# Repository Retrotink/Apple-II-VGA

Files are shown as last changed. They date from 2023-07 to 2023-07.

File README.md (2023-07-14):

<br>appleIIvga github logo
<br>


<br>

This project is a VGA card for Apple II/II+ and //e computers to output a crisp RGB signal to a VGA monitor instead of having to rely on the composite output. This is accomplished by snooping the 6502 bus and creating a shadow copy of the video memory within a Raspberry Pi Pico, then processing the raw video memory contents to output a "perfect" signal. 
<br>
installed
<br>
These features are currently supported:<br>
Generates a 640x480@60 VGA signal with 3 bits per color channel using resistor DACs<br>
Text mode (monochrome)<br>
Lo-res mode with no color fringing between the chunky pixels<br>
Hi-res mode with simulated NTSC artifact color<br>
Mixed lo-res and hi-res modes with monochrome text and no color fringing<br>
Double hi-res and 80 column mode on the //e only<br>
screen demo
<br>

<br>
# Bill Of Materiels<br>
<br>
<br>

BOM

<br>
<br>

# Apple IIe internal Cable<br>

<br>

IIe cable

<br>
<br>

## AMAZON<br>

https://www.amazon.com/dp/B07W3ZTPZ6?psc=1&ref=ppx_yo2ov_dt_b_product_details
<br>

# Soldering the Apple II VGA Card
<br>

## Step 1: The Resistors<br>
resistor
<br>
Resistors are not polarized so they can be installed either direction. I like to start with the 100ohm resistors and work my way up to the 10K ohm resistors. The gold band is the percentage of accuracy. To read a resistor, start at the opposite side of the gold band.<br>
<br>
47 ohm resistors -- qty 2 - Colors Yellow Violet Black<br>
510 ohm resistors - qty 3 - Colors Green Brown Brown<br>
1K ohm resistors -- qty 6 - Colors Brown Black Red<br>
2K ohm resistors -- qty 3 - Colors Red Black Red<br>
10K ohm resistors - qty 4 - Colors Brown Black Orange<br>
Bend the metal wires at a 90 degree angle on each side of the resistor body.<br>
Place the resistor into the resistor location until it is flush with the PCB. <br>
Turn the board over holding the resistor in its place and bend the wires outward just slightly so the resistor can not back out of the holes. <br>
While the bottom of the board is facing up flat on your workspace, solder each of the two wires on the resistor. <br>
Make sure your solder stays only on the resistor wire and the hole. <br>
Cut the excess lead off the resistor. Repeat this procedure for all of the resistors.<br>
<br>
## Step 2: The Voltage Regulator<br>
vr
<br>
Insert the Voltage Regulator and fold it over so it lays flat on its back.<br>
Place the small screw into the top hole and through the board.<br>
Place the nut on the screw on the back of the board and tighten down.<br>
Solder all 3 pins and cut the extra leads short with the board.<br>
<br>
## Step 3: Install the three 20 pin sockets<br>
socket<br>
The socket has a notch on one end that matches the PCB.<br>
Place one socket into position and while holding the socket, turn the board over and lay flat on the table.<br>
Hold the board level and solder 1 pin down. Turn the board over and check that the board is flush with the PCB.<br>
If not, apply heat to the pin while pushing the socket flush to the PCB<br>
Solder the remaining pins on the socket and repeat for the other 2 sockets<br>
<br>
## Step 4: Install the 3 .1uF capacitors<br>
cap 1

Install the three .1uF caps into their locations. The caps are labeled 104 and are not polarized so they can be installed either way.<br> 
Fit as flush as possible, bend the 2 wires apart a little so the capacitor does not fall out, turn the board over and set it on your workspace. <br>
Solder the leads onto the PCB and cut away the excess lead length.<br>
<br>
## Step 5: Install the 10uF Electrolytic Capacitor<br>
cap10

## CAUTION: The capacitor is polarized and must be installed correctly. <br>
It is cylinder shaped and both leads protrude from the same side and are labeled 10uF. <br>
There are two ways to tell the + and - leads. <br>
First, looking at the leads, the + is longer than the – lead. <br>
Secondly, there is a large white arrow pointing to the - lead. <br>
Install flush with the PCB and fold it over so it lays between the .1uF cap and the voltage regulator.<br>
Then bend the two leads slightly apart from one another. <br>
Turn the board over and solder onto the PCB. Cut the excess lead on the capacitor.<br>
<br>
## Step 6: Install the Raspberry Pi Pico board<br>
pico
<br>
<br>
## CAUTION: Verify correct orientation before soldering down the Rasperry Pi Pico!<br>
Place the two 20 pin stand offs onto the board.<br>
Then place the Pico onto the stand offs and make sure everything fits flush.<br>
The Pico should be facing with the USB connector towards the VGA connector location.<br>
Solder the 40 pins onto the Pico then hold down the Pico, flip the board and solder the pins to the PCB<br>
<br>
## Step 7: Install the VGA connector<br>
vga

The VGA connector has 3 rows of pins. <br>
Insert flush with PCB, turn and solder the inside row first, followed by the outer 2 rows. <br>
Check your work, and then solder the support tabs down.<br>
<br>
## Step 8: Install the 74LVC245 Buffer IC's into the sockets<br>
You will need to pin the pins slightly inwards to align with the sockets.<br>
## CAUTION: Make sure all the IC's are facing towards the Voltage Regulator.<br>
Check for bent pins. Check for missing solder points<br>
<br>
## Solderfest 202/// all Pico chips are preprogrammed for the apple //e and will work on the apple ][ plus<br>
<br>
If you wish to program or update:<br>
1. Press and hold the BOOTSEL button on the Pico while plugging into PC<br>
2. A drive will appear on the PC called RPI-RPI2. Simply drag the *.UF2 firmware file to the RPI drive. <br>
3. The RPI drive will then disappear<br>
4. Remove the USB cable place the Apple ][ VGA card in your Apple ][
<br>

## Acknowledgements

Original design by Mark Aikens. Some minor modifications were made and a board layout made using original PI Pico source code. All parts are through hole for easy assembly. No surface mount components, simple to build.
<br>
https://github.com/markadev/AppleII-VGA
<br>
## Build at your own Risk

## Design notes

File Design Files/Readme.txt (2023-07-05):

Board size: 4.5W X 2.5H

Files:

AppleIIVGAf.GBL	Bottom Layer
AppleIIVGAf.GBS	Bottom Solder
AppleIIVGAf.GM1	Board outline
AppleIIVGAf.GTL	Top Layer
AppleIIVGAf.GTO	Top Overlay
AppleIIVGAf.GTS	Top Solder
AppleIIVGAf.TXT	Drill File

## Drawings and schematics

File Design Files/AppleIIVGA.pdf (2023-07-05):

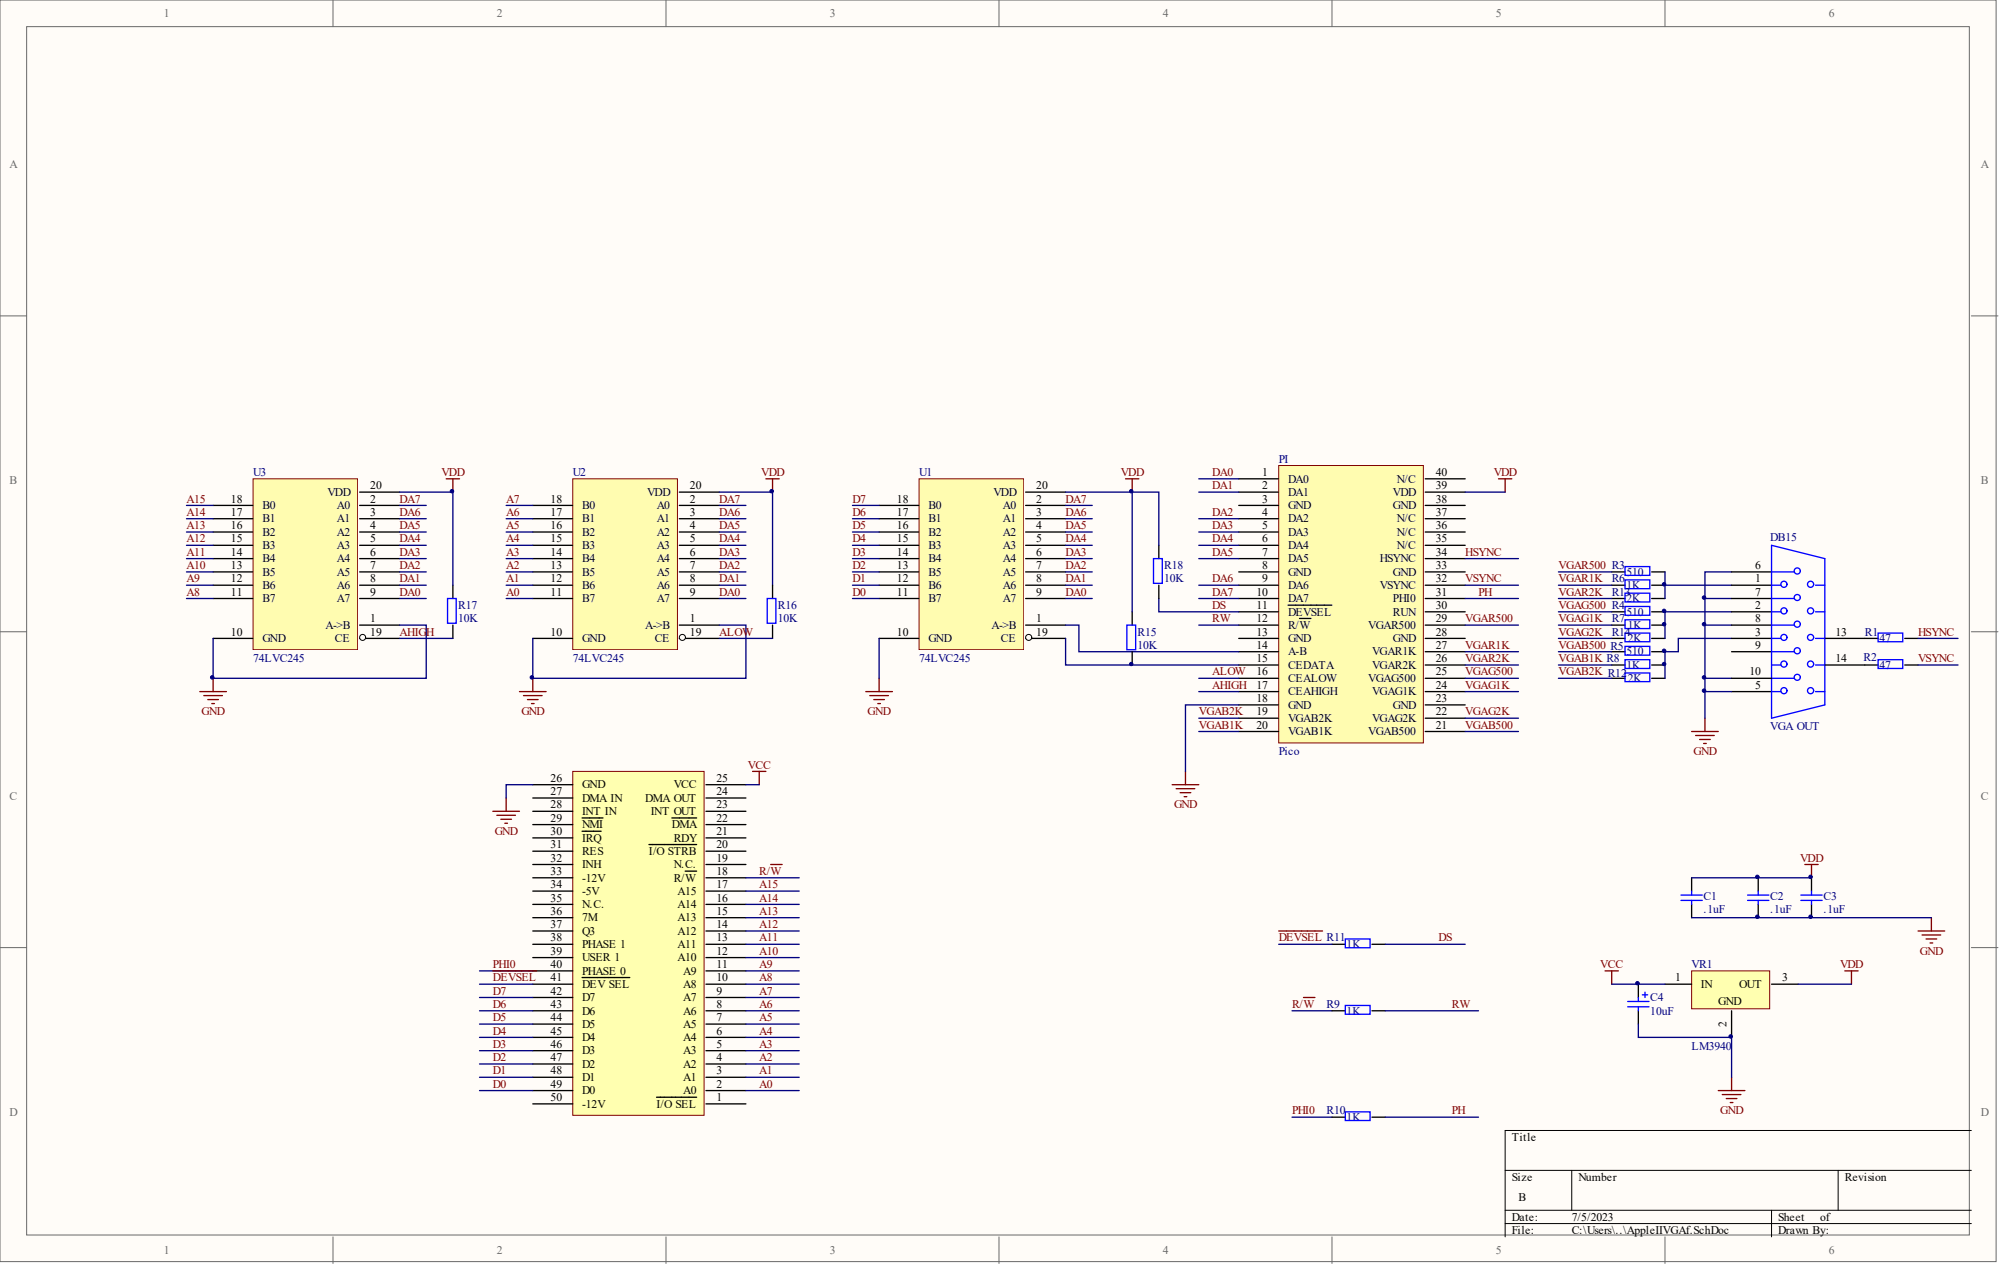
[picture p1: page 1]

4 | DA2 DA3 DA4 DA5 DA6 DA7 | A7 A6 A5 A4 A3 A2 A1 A0 1 6 | 4 | DA7 DA6 DA5 DA4 DA3 DA2 DA1
3 | | 1 7 | 3

7 | | 1 3 | | 7
8 | DA 1 | 1 2 | | 8

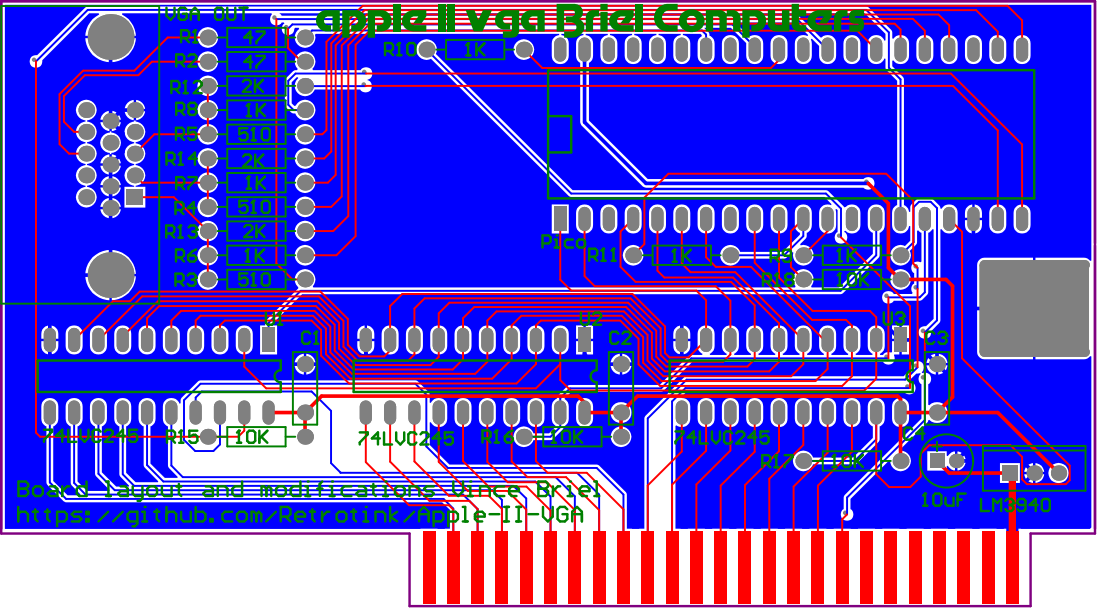
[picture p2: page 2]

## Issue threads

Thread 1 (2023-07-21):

Question about this version of VGA

TedThompson, 2023-07-21:
https://github.com/V2RetroComputing/analog/issues/19#issue-1799680730

The issue above occurs with a more complex version of this card which has a GAL for some device selection logic tricks which I think are required for uploading to and configuring the Raspberry Pi using programs running on the Apple.

Features I won't really use.

I'm wondering if this version exhibits the same funny behavior with HGR2?

I also wonder if, since it doesn't seem this version of the card does anything in the card ROM space, if it can live in Slot 3 of a //e without issue?

dkgrizzly, 2023-08-28:
I believe you are having a conflict between the 80 column firmware on the motherboard and the VGA card.  I would advise against placing any cards in slot 3 on a IIe which use the ROM address space, as this can cause conflicts. There are specific guidelines in the Apple Tech Notes for the IIe about how to avoid these conflicts, which this card (and many others) does not currently implement.

TedThompson, 2023-08-28:
Understood. Thanks.

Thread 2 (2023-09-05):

Pico source code

ivorss, 2023-09-05:
Is this project open-source when it comes to the software?

If yes, could you please add the source code of the Pico as well? As I understand you have modified the original found in https://github.com/markadev/AppleII-VGA/tree/main/pico

Thanks!

ivorss, 2023-10-29:
I did not realize that the Pico source code was not changed in this branch. Closing, since it's not an issue.

Closed 2023-10-29.

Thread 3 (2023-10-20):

Add 5V to pin 9 of VGA DSUB for powering HDMI adapters

Alex-Kw, 2023-10-20:
It's useful to be able to directly power a (modified) VGA -> HDMI adapter from the Apple II's VGA port.

The VGA standard allows for 5V on pin 9. Could the gerber files be updated to add this trace?
